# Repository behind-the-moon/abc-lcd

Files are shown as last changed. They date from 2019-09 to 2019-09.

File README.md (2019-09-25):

## BOOOM !!!

It worked some time, until I've decided to test shorts....
-----

I don't recommend this project, maybe, someday I make something better.

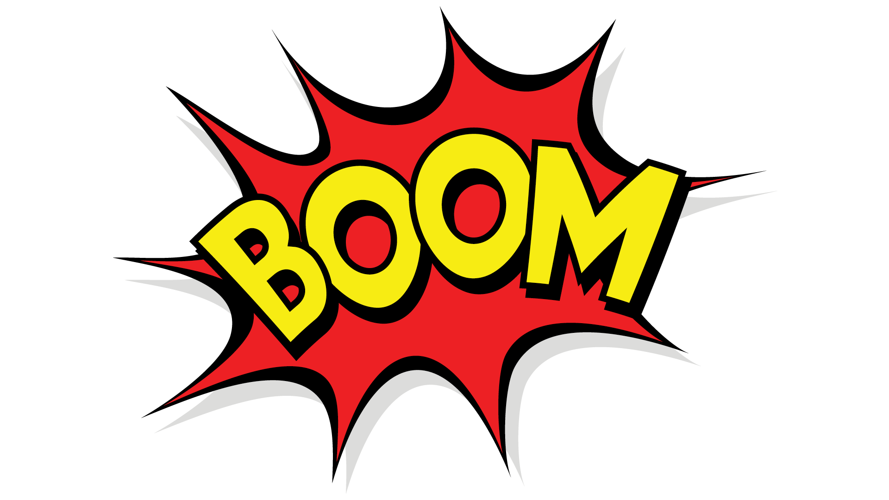
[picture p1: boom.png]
boom


The screenshot of schematic for easier access to it

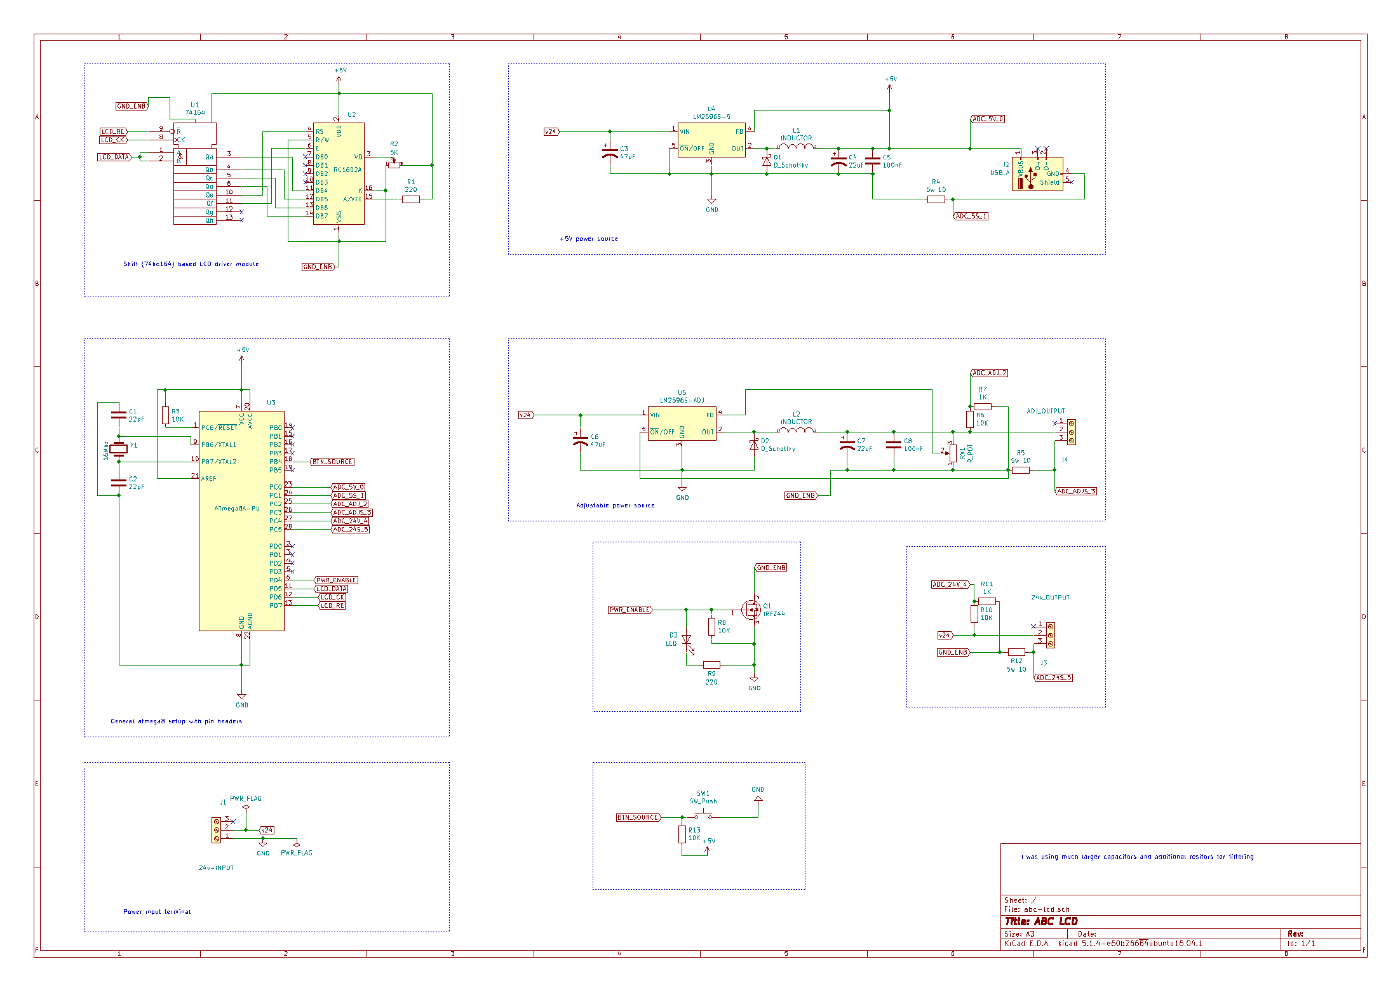
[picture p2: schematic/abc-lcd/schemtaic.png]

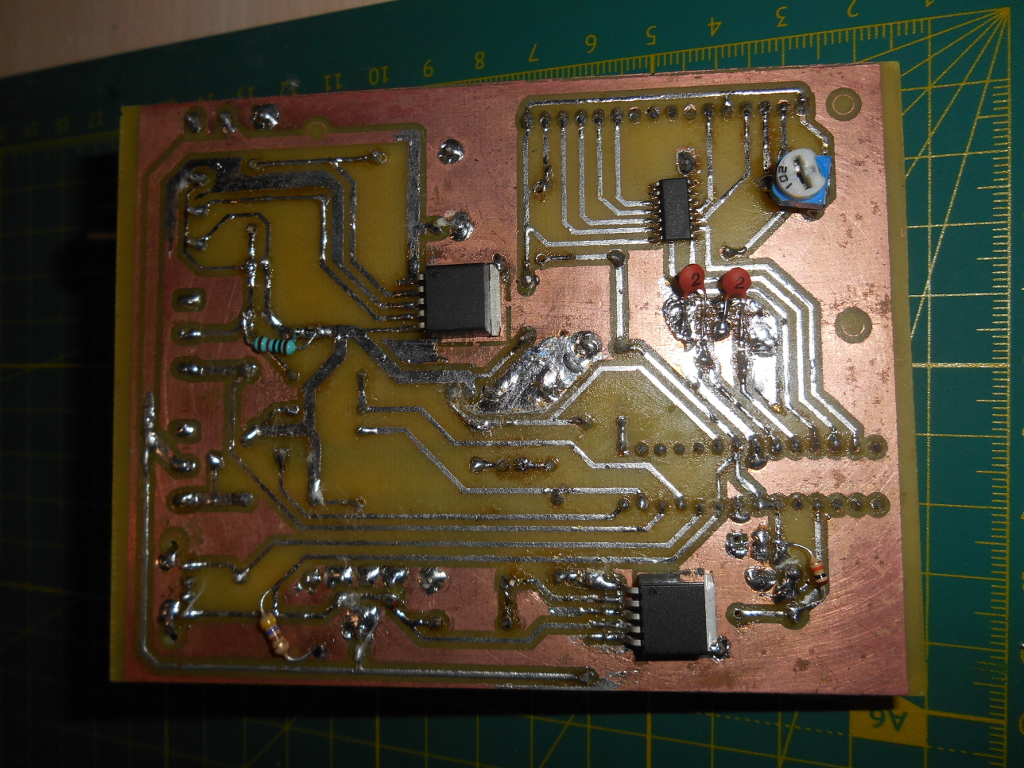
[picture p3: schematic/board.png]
board


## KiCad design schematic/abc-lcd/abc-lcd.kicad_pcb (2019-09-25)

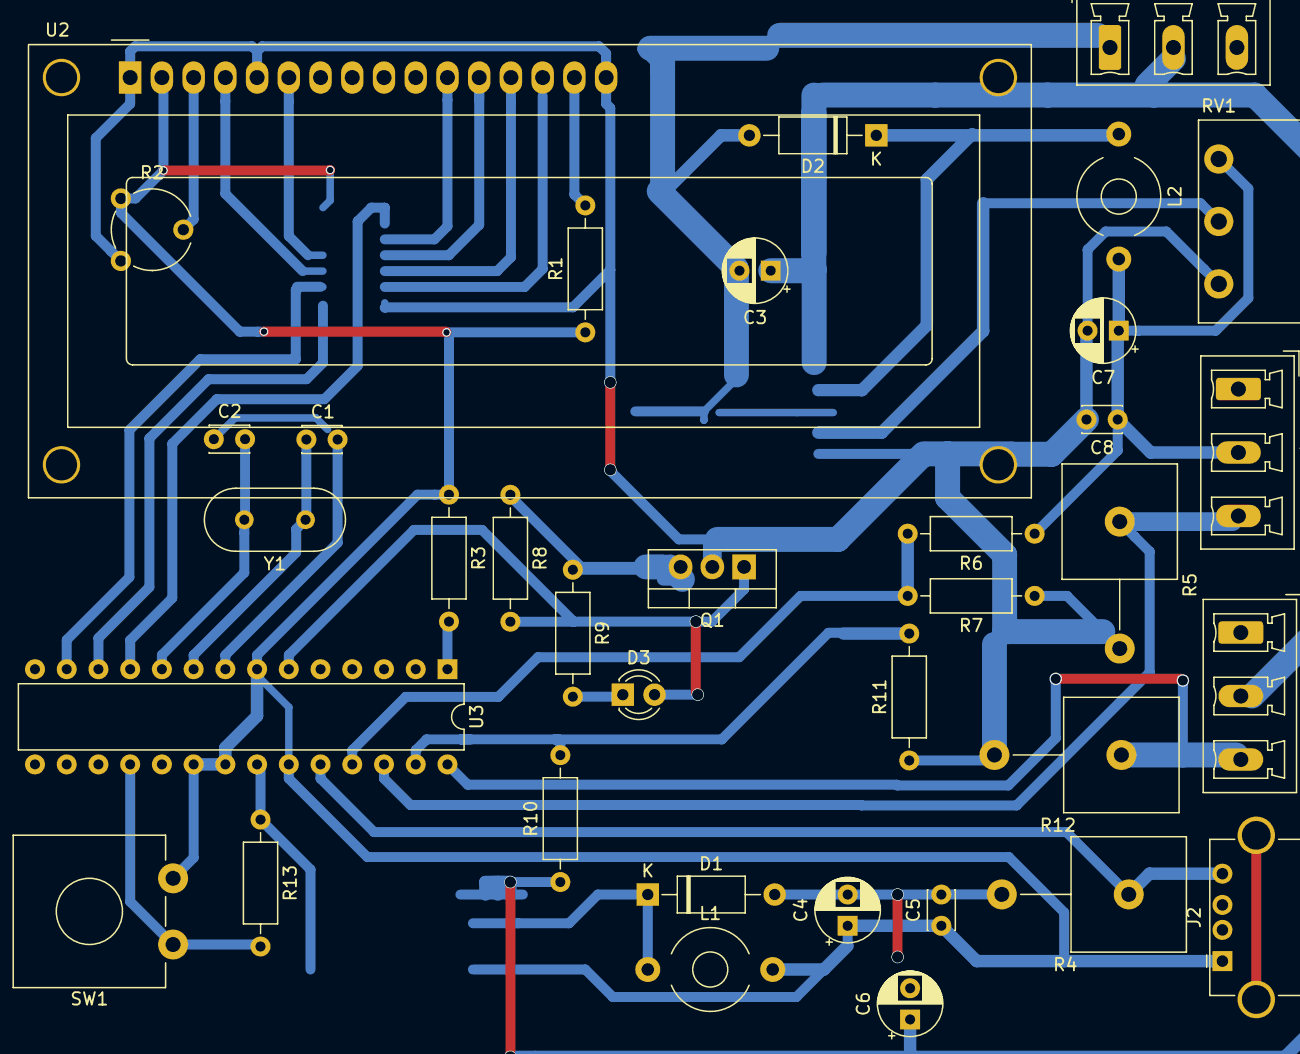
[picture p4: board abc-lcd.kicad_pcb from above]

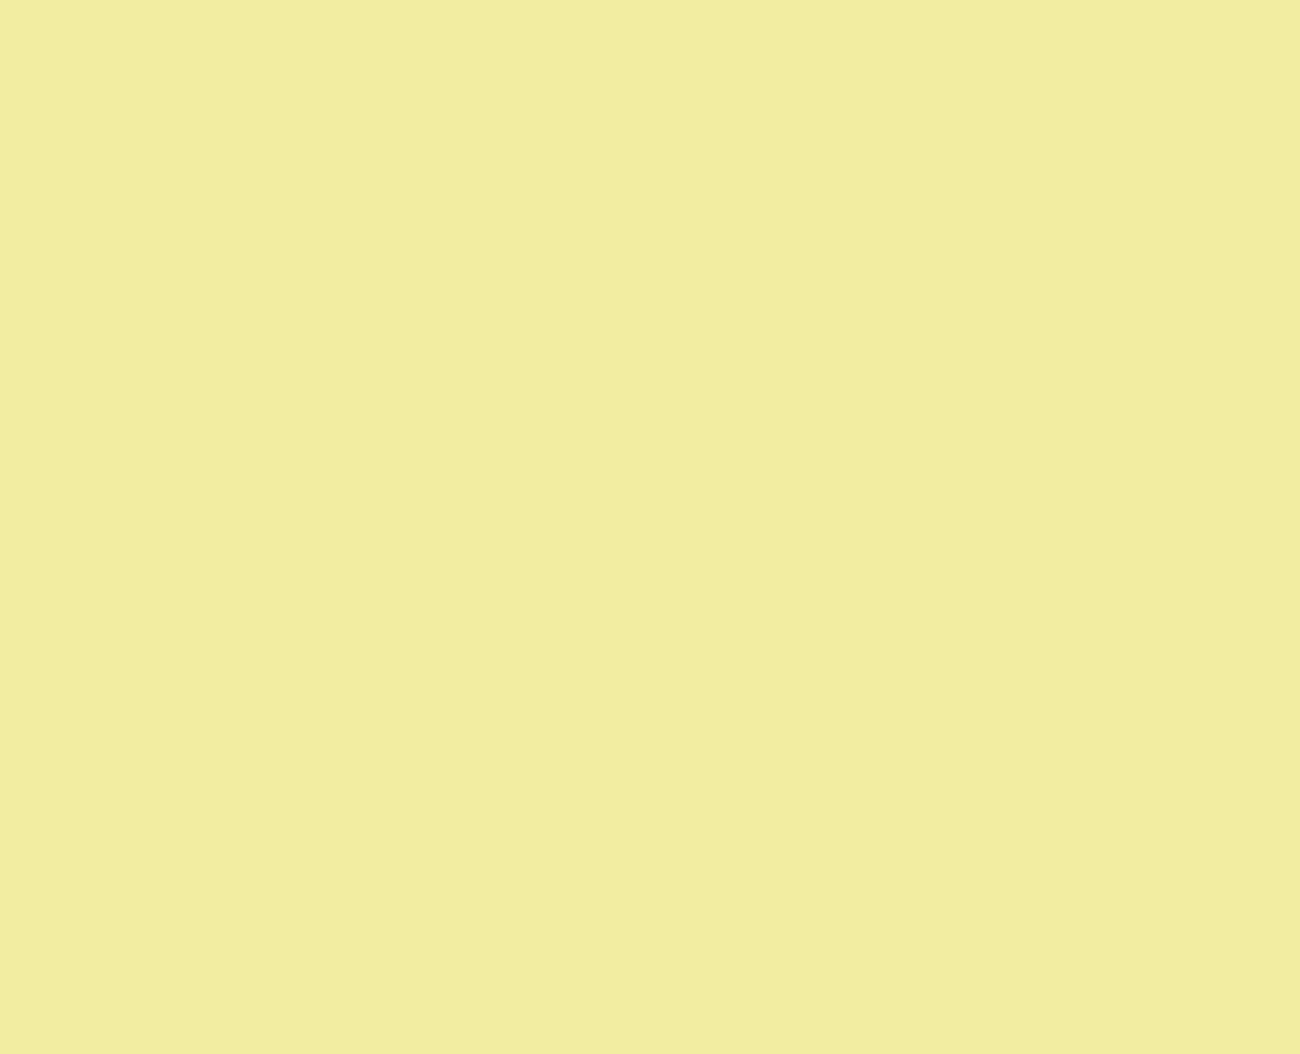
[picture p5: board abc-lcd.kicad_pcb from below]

Board: 2 copper layers, 39 parts (3 on the bottom side), 30 nets.

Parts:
C1, C2: 22pF; C_Disc_D3.0mm_W2.0mm_P2.50mm
C3, C6: 47uF; CP_Radial_D5.0mm_P2.50mm
C4, C7: 22uF; CP_Radial_D5.0mm_P2.50mm
C5, C8: 100nF; C_Disc_D3.0mm_W2.0mm_P2.50mm
D1, D2: D_Schottky; D_A-405_P10.16mm_Horizontal
D3: LED; LED_D3.0mm_FlatTop
J1: 24v-INPUT; PhoenixContact_MCV_1,5_3-G-5.08_1x03_P5.08mm_Vertical
J2: USB_A; USB_A_Stewart_SS-52100-001_Horizontal
J3: 24v_OUTPUT; PhoenixContact_MCV_1,5_3-G-5.08_1x03_P5.08mm_Vertical
J4: ADJ_OUTPUT; PhoenixContact_MCV_1,5_3-G-5.08_1x03_P5.08mm_Vertical
L1, L2: INDUCTOR; L_Toroid_Horizontal_D6.5mm_P10.00mm_Diameter7-5mm_Amidon-T25
Q1: IRFZ44; TO-220-3_Vertical
R1, R9: 220; R_Axial_DIN0207_L6.3mm_D2.5mm_P10.16mm_Horizontal
R2: 5K; Potentiometer_Piher_PT-6-V_Vertical
R3, R6, R8, R10, R13: 10K; R_Axial_DIN0207_L6.3mm_D2.5mm_P10.16mm_Horizontal
R4, R5, R12: 5w 10; R_Axial_Power_L25.0mm_W9.0mm_P10.16mm_Vertical
R7, R11: 1K; R_Axial_DIN0207_L6.3mm_D2.5mm_P10.16mm_Horizontal
RV1: R_POT; Potentiometer_Piher_PC-16_Single_Horizontal
SW1: SW_Push; SW_CW_GPTS203211B
U1: 74164; SOIC-14_3.9x8.7mm_P1.27mm
U2: RC1602A; WC1602A
U3: ATmega8A-PU; DIP-28_W7.62mm
U4: LM2596S-5; TO-263-5_TabPin3
U5: LM2596S-ADJ; TO-263-5_TabPin3
Y1: 16Mhz; Crystal_HC18-U_Vertical

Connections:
ADC_5S_1: J2.4, R4.1, U3.24
ADC_5V_0: C4.1, C5.1, J2.1, L1.2, R1.1, R2.3, R3.1, SW1.2, U1.14, U2.2, U3.7, U3.20, U3.21, U3.23, U4.4
ADC_24S_5: J3.3, R12.1, U3.28
ADC_24V_4: R10.2, R11.2, U3.27
ADC_ADJS_3: J4.3, R5.1, U3.26
ADC_ADJ_2: R6.2, R7.2, U3.25
BTN_SOURCE: R13.2, SW1.1, U3.18
GND: C1.1, C2.2, C3.2, C4.2, C5.2, C6.2, D1.2, D2.2, J1.1, Q1.3, R4.2, R8.1, R9.1, R13.1, U3.8, U3.22, U4.3, U4.5, U5.3
GND_ENB: C7.2, C8.2, Q1.2, R2.1, R5.2, R7.1, R11.1, R12.2, RV1.1, U1.7, U2.1, U2.5, U2.16, U5.5
LCD_CK: U1.8, U3.12
LCD_DATA: U1.1, U1.2, U3.11
LCD_RE: U1.9, U3.13
unnamed: C1.2, U3.9, Y1.1
unnamed: C2.1, U3.10, Y1.2
unnamed: C7.1, C8.1, J4.2, L2.2, R6.1, RV1.3
unnamed: D1.1, L1.1, U4.2
unnamed: D2.1, L2.1, U5.2
unnamed: D3.1, R9.2
unnamed: R1.2, U2.15
unnamed: R2.2, U2.3
unnamed: R3.2, U3.1
unnamed: RV1.2, U5.4
unnamed: U1.3, U2.11
unnamed: U1.4, U2.12
unnamed: U1.5, U2.13
unnamed: U1.6, U2.14
unnamed: U1.10, U2.4
unnamed: U1.11, U2.6
PWR_ENABLE: D3.2, Q1.1, R8.2, U3.6
v24: C3.1, C6.1, J1.2, J3.2, R10.1, U4.1, U5.1

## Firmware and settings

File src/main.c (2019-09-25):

/*********************************************************************************
 * File Name     : main.c
 * Created By    : Svetlana Linuxenko
 * Creation Date : [2019-09-20 23:23]
 * Last Modified : [2019-09-25 18:31]
 * Description   :  
 **********************************************************************************/

//#define DEBUG

#include <avr/io.h>
#include <avr/wdt.h>
#include <avr/interrupt.h>
#include <util/delay.h>
#include <stdio.h>

#include "shiftout.h"
#include "lcdshift.h"
#include "tools.h"
#include "atmega-adc.h"

#ifdef DEBUG
#include "uart.h"
#define _BAUD_RATE   9600
#endif

#define LCD_UPDATE_INTERVAL 40000

const float factor[] = {
  1, // ADC0 factor
  10,
  11,
  10,
  11,
  10
};

ShiftIC icS;
ShiftLCD lcd;
uint8_t pwr_state = 0;

#define ADC_PORTS 6
uint16_t voltages[ADC_PORTS];

void adc_update(uint8_t pin, uint16_t value) {
  voltages[pin] = value;
}

void lcd_update(void) {
  char text[16]; // Just a line
  char values[ADC_PORTS][6];
  uint8_t i = 0;

  if (!pwr_state) {
    return;
  }
  // Full refresh
/*  shiftLCDClear(&lcd);*/
  shiftLCDSetCursor(&lcd, 0, 0);

  /*
   * Lets fill values depending on adc factors such
   * as voltage dividers and their leakage measured
   * individually because they're may vary
   */

  for (; i < ADC_PORTS; i++) {
    float_to_str(values[i], (((voltages[i] * 5.00) / 1023.00) * factor[i]));
  }

  sprintf(text, "V %s %s %s", values[0], values[2], values[4]);

  shiftLCDPuts(&lcd, text);
#ifdef DEBUG
  uart_puts(text);
  uart_puts("\r\n");
#endif

  sprintf(text, "A %s %s %s", values[1], values[3], values[5]);

  shiftLCDSetCursor(&lcd, 0, 1);
  shiftLCDPuts(&lcd, text);

#ifdef DEBUG
  uart_puts(text);
  uart_puts("\r\n");
  uart_flush();
#endif
}

void lcd_init(void) {
  createShiftLCD(&lcd, &icS, 4, 5, 0, 1, 2, 3, 16, 2, 0);
}


void pwr_toggle() {
  pwr_state ^= 1;

  if (pwr_state == 0) {
    PORTD &= ~(1 << PD4);
  } else {
    PORTD |= (1 << PD4);
    lcd_init();
  }
}

int main(void) {
  unsigned long lup_count = 0;
  uint8_t pwr_confidence = 0;

#ifdef DEBUG
  uart_init(UART_BAUD_SELECT(_BAUD_RATE, F_CPU));
#endif

  DDRB &= ~(1 << PINB4);
  DDRD |= (1 << PORTD4);
  PORTD &= ~(1 << PORTD4);

  /* ADC with updatable callback (awesome stuff) */
  adc_start(ADC_PRESCALER_128, ADC_VREF_AVCC, ADC_PORTS, adc_update);

  /* LCD initalization */
  createShift(&icS, &DDRD, &PORTD, PORTD5, PORTD6, PORTD7);
  icS.type = IC_TYPE_HC164;
  lcd_init();

  wdt_enable(WDTO_2S);
  sei();

  while(1) {
    wdt_reset();

    /* Kinda simpliest debounce */
    if ((PINB & (1 << PINB4)) == 0 && pwr_confidence == 0) {
      pwr_confidence = 1;
      pwr_toggle();
    }

    if (lup_count >= LCD_UPDATE_INTERVAL) {

      if (pwr_confidence != 0 && (pwr_confidence++) >= 3) {
        pwr_confidence = 0;
      }

      lup_count = 0;
      lcd_update();
    }

    lup_count++;
    _delay_us(10);
  }

  return 0;
}

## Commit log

2019-09-21 ADC library that works
2019-09-21 Just a voltmeter
2019-09-22 Power module schematic
    [abc-lcd.kicad_pcb, abc-lcd.sch]
2019-09-22 A bit less messy pcb but still looks like a garbage
    [abc-lcd.kicad_pcb, abc-lcd.sch]
2019-09-23 Proper component placement
    [abc-lcd.kicad_pcb, abc-lcd.sch]
2019-09-23 Complete pcb (alpha)
    [abc-lcd.sch]
2019-09-23 Smaller version (not testerd yet)
    [abc-lcd.kicad_pcb, abc-lcd.sch]
2019-09-24 Schematic with 2 missing capacitors (tested)
    [abc-lcd.kicad_pcb, abc-lcd.sch]
2019-09-24 Power button support
2019-09-25 Pwr button behaviour fix
    [main.c]
2019-09-25 Schematic image
    [abc-lcd.sch]
2019-09-25 Board image
